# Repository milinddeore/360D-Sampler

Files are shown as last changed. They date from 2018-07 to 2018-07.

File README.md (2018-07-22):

# 360D-Sampler
Takes snaps of the product/item from 360 degree.

## Overview
If data is oil, machine learning is oil refinery! 

To generate your own image data for a specific object/product/item. We have created this project, that captures 360 degree images of an object. The work is based on the image capturing details given in the [paper](https://drive.google.com/drive/folders/0B8z-ghcMsu59RjNtS1VzN1Zpb0U) 

This sampler is meant for image sampling that can be later used for training an image classifier. To get best quality and appropriate image samples the paper concludes following: 

* Azimuth - Object should be revolved 360 degree at least 24 times in equal angle. This means 360/24 = 15 degree.
* Elevation - In a circular fashion object should be captured in four verticals i.e. 90 degree / 4 = 22.5 degree.

## Repo Contains

1. Word document that gives high level details about the sampler. 
2. Mechanical Design: CAD file of the sampler design along with BOM
3. Source code to run controller and DSLR controller software to capture pictures. 

## Working Flow

Following actions and events occur during sampling: 

1. Place the object on the revolving table top,
2. Enter the barcode so that the respective folder will be created with the name as ‘barcode #’. Else enter manual name. 
3. Follow the on-screen messages to let table top to start revolving and Cameras will start capturing images. There are total 5 cameras capturing images in tandem. 
4. Once 360 degree movement is over, the table top stops.
5. To capture another object jump to step 1.

## Physical Images Of The Sampler

Following images are of the physical sampler that was manufactured for demo purpose. 

Design



## Software

1. Arduino: To control the motor and clicker. This code is in the ‘arduino’ directory.
2. DSLR controller: This project uses libgphotos2 to control all the DSLR mounted on the hardware chassis. This code runs on the PC/Laptop and the application code is in the following path ‘slrs/examples/sample-capture.c’ 

## Compile and Install

1. Follow the [link](https://github.com/gphoto/libgphoto2/blob/master/INSTALL) to compile the code, that run on PC.   
2. Arduino code needs to be flashed onto Aruino UNO or any of the similar version. 

## Contributors
Saket Deshmukh (Saaket.deshmukh@gmail.com)
Milind Deore (tomdeore@gmail.com)

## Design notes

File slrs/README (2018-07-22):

# README #

This README would normally document whatever steps are necessary to get your application up and running.

### What is this repository for? ###

* This is DSLR based product sampler, which takes snaps of the product from 360 degree. This requires a rotating top where the product is placed while capturing pictures. This software also needs a hardware barcode scanner, optinally user can enter the product name/barcode manually too.
* This is tested version 1.0
* [Learn Markdown](https://bitbucket.org/tutorials/markdowndemo)

### How do I get set up? ###

* Summary of set up: rotating top, hardware barcode scanner, tripods and ubuntu based machine. 
* Configuration: Please see the setup.installation file for details. 
* Dependencies: None
* Database configuration: None
* How to run tests: go to ./examples/ directory of the project and run 'sample-capture' program. This program also has various options run 'sample-capture -u' to lean more.
* Deployment instructions: Follow the drawing atttached to the repo for details. 

### How to compile and install libgphotos2 and sampler application

* Compile and install as per mentioned [here](https://github.com/gphoto/libgphoto2/blob/master/INSTALL)

### Troubleshooting 

If you got this error running apt-get or some other program:
perl: warning: Setting locale failed.
perl: warning: Please check that your locale settings:

Just run this code:
export LANGUAGE=en_US.UTF-8
export LANG=en_US.UTF-8
export LC_ALL=en_US.UTF-8
locale-gen en_US.UTF-8
dpkg-reconfigure locales

### Contribution guidelines ###

* Writing tests
* Code review
* Other guidelines

### Who do I talk to? ###

* Repo owner or admin
* Other community or team contact

				   libgphoto2
				   ----------

Hello and welcome to the wonderful world of gphoto! This is libgphoto2, the 
successor of gphoto with lots of new features and additional camera
drivers. 

If you miss a feature, would like to report success or failure, or have any
questions, please don't hesitate to contact our mailing list.

What is libgphoto2?
-------------------

libgphoto2 is a library that can be used by applications to access various 
digital cameras.  

For more information on gphoto, see

        http://www.gphoto.org/

There, you can also get information on mailing lists, supported cameras,
and availability of gphoto2. Another source of information is

        https://github.com/gphoto

where you can access our SVN server to fetch the source code of
gphoto2, gtkam and GnoCam (see below).

What is libgphoto2 not?
-----------------------

libgphoto2 itself is not a GUI application, opposed to gphoto. There are
GUI frontends for the gphoto2 library, however, such as gtkam for
example.

libgphoto2 can only talk to cameras the language of those it understands.
That is, if you own a camera that speaks a language that isn't published
anywhere and nobody has been able to figure out the meaning of the sentences,
libgphoto2 cannot communicate with those cameras. 

Then, there are cameras supporting the so-called USB Mass Storage protocol.
This is a protocol that has been published and lets you access any storage
device, be it a camera or a disk connected via USB to your computer. As there
are already drivers for this protocol out there, you don't need an additional
library like libgphoto2. The list of camera that use USB Mass Storage is getting
longer everyday, so we won't publish it.

For a more up to date list, you can consult 

	http://www.teaser.fr/~hfiguiere/linux/digicam.html

Your operating system will tell you about that because it is likely to recognise
the device as a SCSI disk that you can mount (for Linux 'dmesg' will tell you).
Again, those cameras *cannot* be accessed through libgphoto2. Some of them can
be switched to use a different communication protocol and might be in that case
useable with libgphoto2.

Other camera support a protocol called PTP or USB Imaging Devices that has
been developped by Kodak and other. libgphoto2 does support PTP. Also working
will be cameras labeled as "PictBridge", which is a extension to PTP.

Almost all cameras that are not mass storage support it these days, including
but not limited to all Nikon, Canon, Fuji, Sony, Panasonic, HP and more.

PTP camera unknown to libgphoto2 will be detected as a generic PTP camera and
will work as-is without any changes.

MTP (Microsoft Transfer Protocol) capable devices will also be accessible,
since MTP is based on PTP.

Platforms
---------

libgphoto2 should compile and run on pretty much all Unix-like platforms.
libgphoto2 has _not_ (yet?) been ported to any operating system from MicroSoft.

How to set up libgphoto2
------------------------

For information on how to set up libgphoto2 and its frontends, see 
The gPhoto2 Manual.

It is available at the following places:

 - At the gphoto website: http://www.gphoto.org/

 - In the SVN module gphoto2-manual

The gPhoto2 Manual includes information about setting up USB
hotplugging.

If you run into problems, you may also consult the FAQ (also included
in The gPhoto2 Manual).

Frontends
---------

gphoto2 is a command line frontend which is quite powerful, 
especially in combination with scripts. See The gPhoto2 Manual 
for a short description. 

For the GUI lovers, there are for example digikam (KDE), gthumb (GNOME),
f-spot (GNOME / Mono) and more. We also have a GTK2 reference GUI
called gtkam, which is unmaintained, its only special features are
capture abilitiy.
Additionally, there are plugins for other programs available like
kio_camera (KDE - Konqueror) and a fuse plugin, gphotofs.

Reporting Bugs
--------------

Every piece of software contains errors and flaws. So does
libgphoto2. When you encounter something that does not work, please do
the following: 

1. Find out whether this is a known problem.

2. Reproduce the problem with debug output enabled and the language
   set to English, so that the development team will understand the
   messages. You can do this by running:

      env LC_ALL=C gtkam

   if you're using the gtkam frontend or running:

      env LC_ALL=C gphoto2 --debug-logfile=logfile.log --debug <options>

   using the gphoto2 command line interface.

3. Report the problem on the mailing list with the corresponding debug
   output if it is small. If it is more than a few kilobytes, please
   don't post the complete debug output on the list.

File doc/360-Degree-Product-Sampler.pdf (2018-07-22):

# 360 Degree Product Sampler

## High Level Design Document

Update document here (https://docs.google.com/document/d/1t0LVbnPOcXeihr9UbaT7DBcxkEmGNjN7Sz3eTbsqpfk/edit?usp=sharing)

# 1.Overview:

This document details required and design for an image sampler based on research paper. (https://drive.google.com/drive/folders/0B8z-ghcMsu59RjNtS1VzN1Zpb0U) This sampler is meant for image sampling that can be later used for training an image classifier. To get best quality and appropriate image samples the paper concludes following:

1. Azimuth - Object should be revolved 360 degree at least 24 times in equal angle. This means 360/24 = 15 degree.
2. Elevation - In a circular fashion object should be captured in four verticals i.e. 90 degree / 4 = 22.5 degree.

# 2.Product Mechanical Drawing:

There are two parts to the design:
- 360 degree revolving tray and,
- Camera arch to hold four cameras, each at 22.5 degree angle in a semi circle.

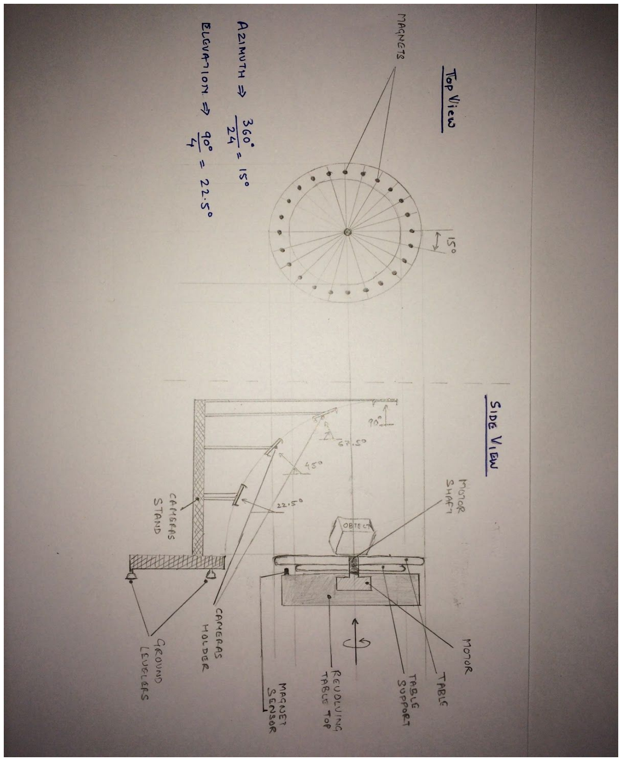
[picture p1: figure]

Revolving tray has 24 magnets each at 15 degree angle and when these magnet cross magnet-sensor, it signals camera to take a snap. These four cameras are mounted on camera stand. Each camera is angled at 22.5 degree in a circular fashion, that is radially all cameras are same distance from the object.

# 3.Bill of Material:

- Stepper motor (https://robu.in/product/nema17-40mm-1-2a-unipolar-stepper-motor-w-1m-cable/) with step size of 15 degree per step.
- Arduino UNO Board.
- Relay (https://www.amazon.in/gp/product/B00C59NOHK/ref=oh_aui_detailpage_o01_s00?ie=UTF8&psc=1)
- Lazy Susan Bearings. (http://www.amazon.in/Susan-Bearings-Thick-200-lb-Capacity/dp/B0006LBVDI)
- We can use five high speed cameras or digital cameras (DSLRs) for our purpose.

# 4.Various Circuits:

Motor, Arduino and DSLR camera all are connected to PC/Laptop via USB cable. USB HUB may be required if the port are not enough on the PC/Laptop.

The circuit has to be connected as per the specification:
1. Arduino and stepper motor interface. (https://www.tutorialspoint.com/arduino/arduino_stepper_motor.htm)
2. Other DSLR’s (http://www.doc-diy.net/photo/remote_pinout/)

# 5.Working flow:

Following actions and events occur during sampling:

1. Place the object on the revolving table,
2. Enter the barcode so that the respective folder will be created with the name as ‘barcode #’
3. Follow the on screen messages to switch ON the motor and image capturing.
4. Once 360 degree movement is over, the motor stops.
5. To capture another object jump to step 1.

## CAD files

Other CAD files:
cad_design/3d-Sampler-Mech-Design.dwg

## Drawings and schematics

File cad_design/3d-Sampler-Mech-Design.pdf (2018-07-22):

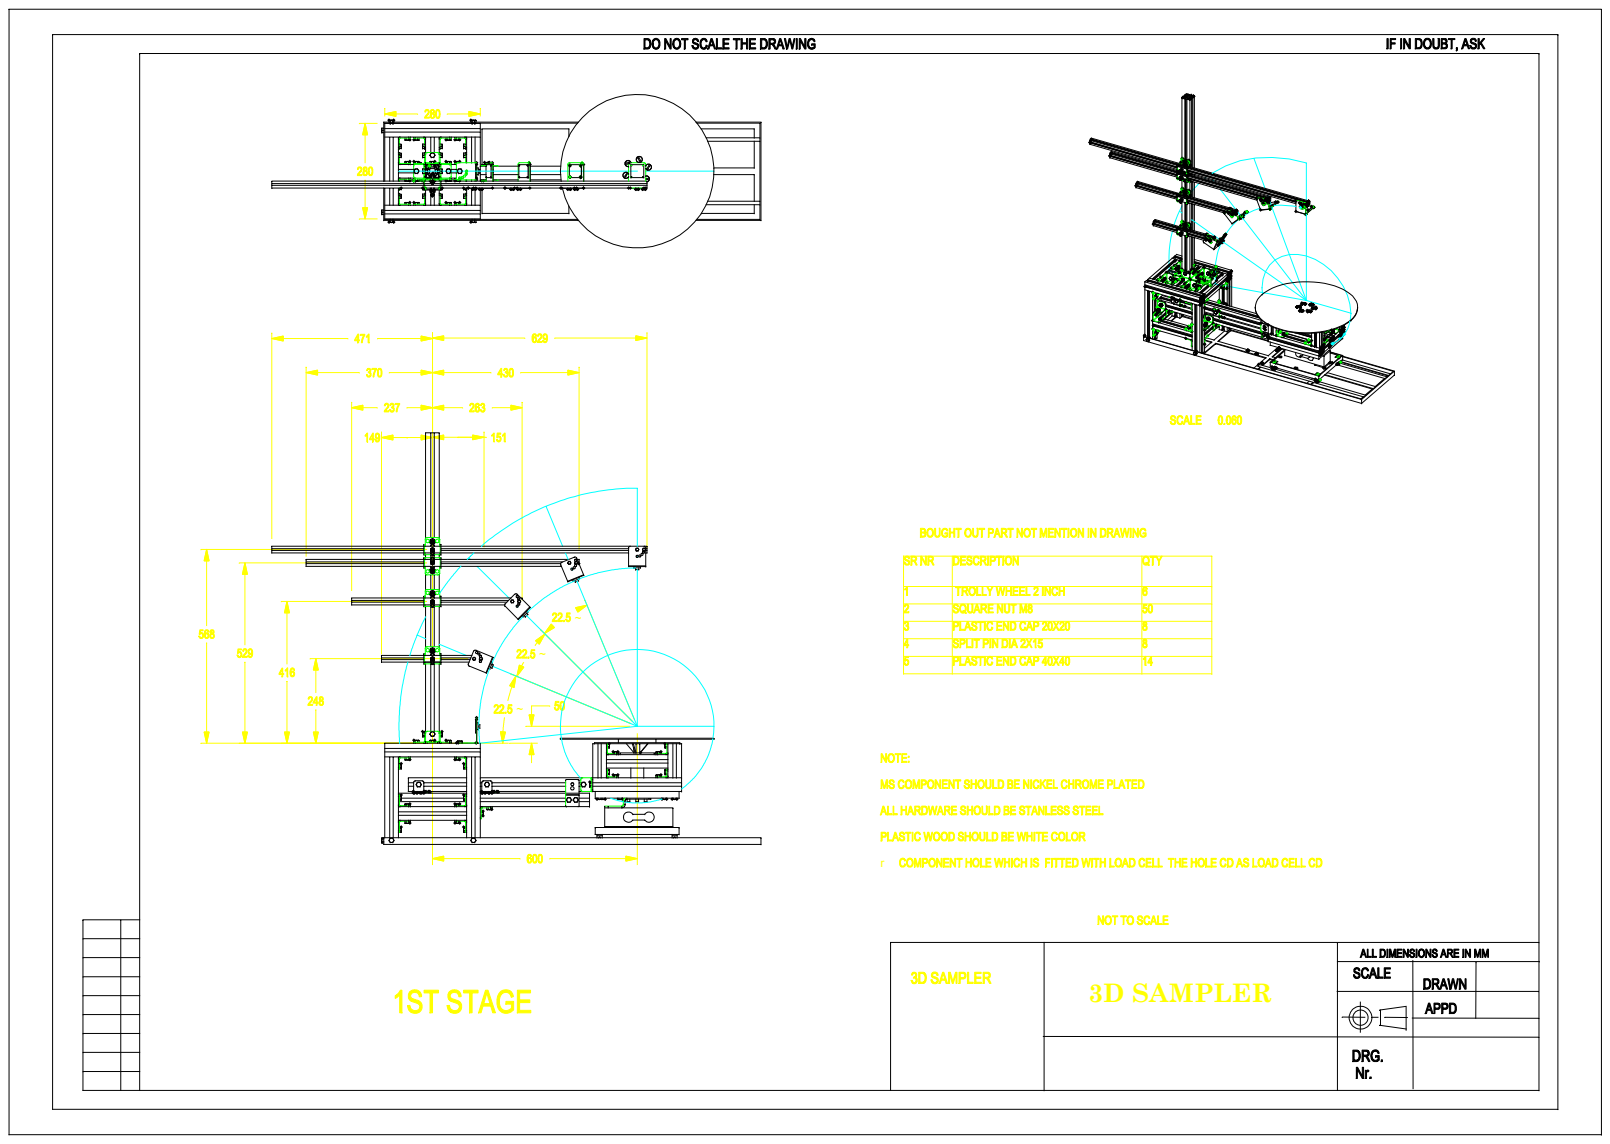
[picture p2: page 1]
3D SAMPLER

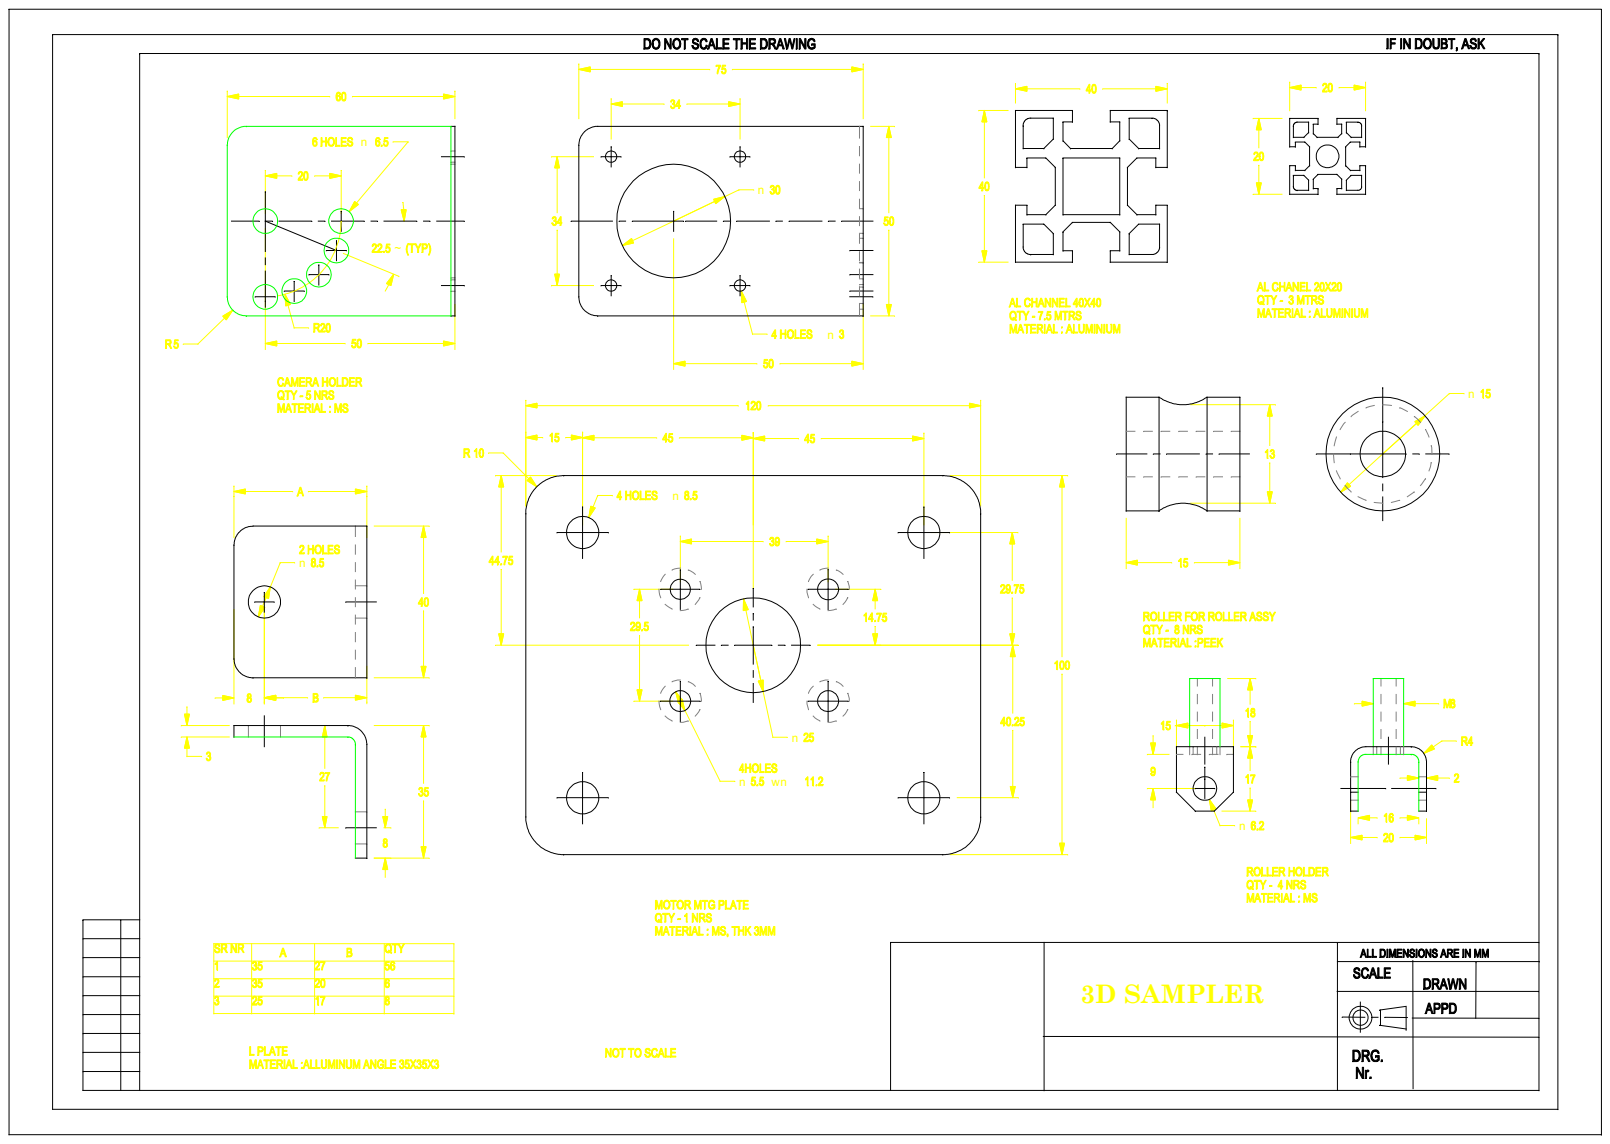
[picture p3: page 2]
3D SAMPLER

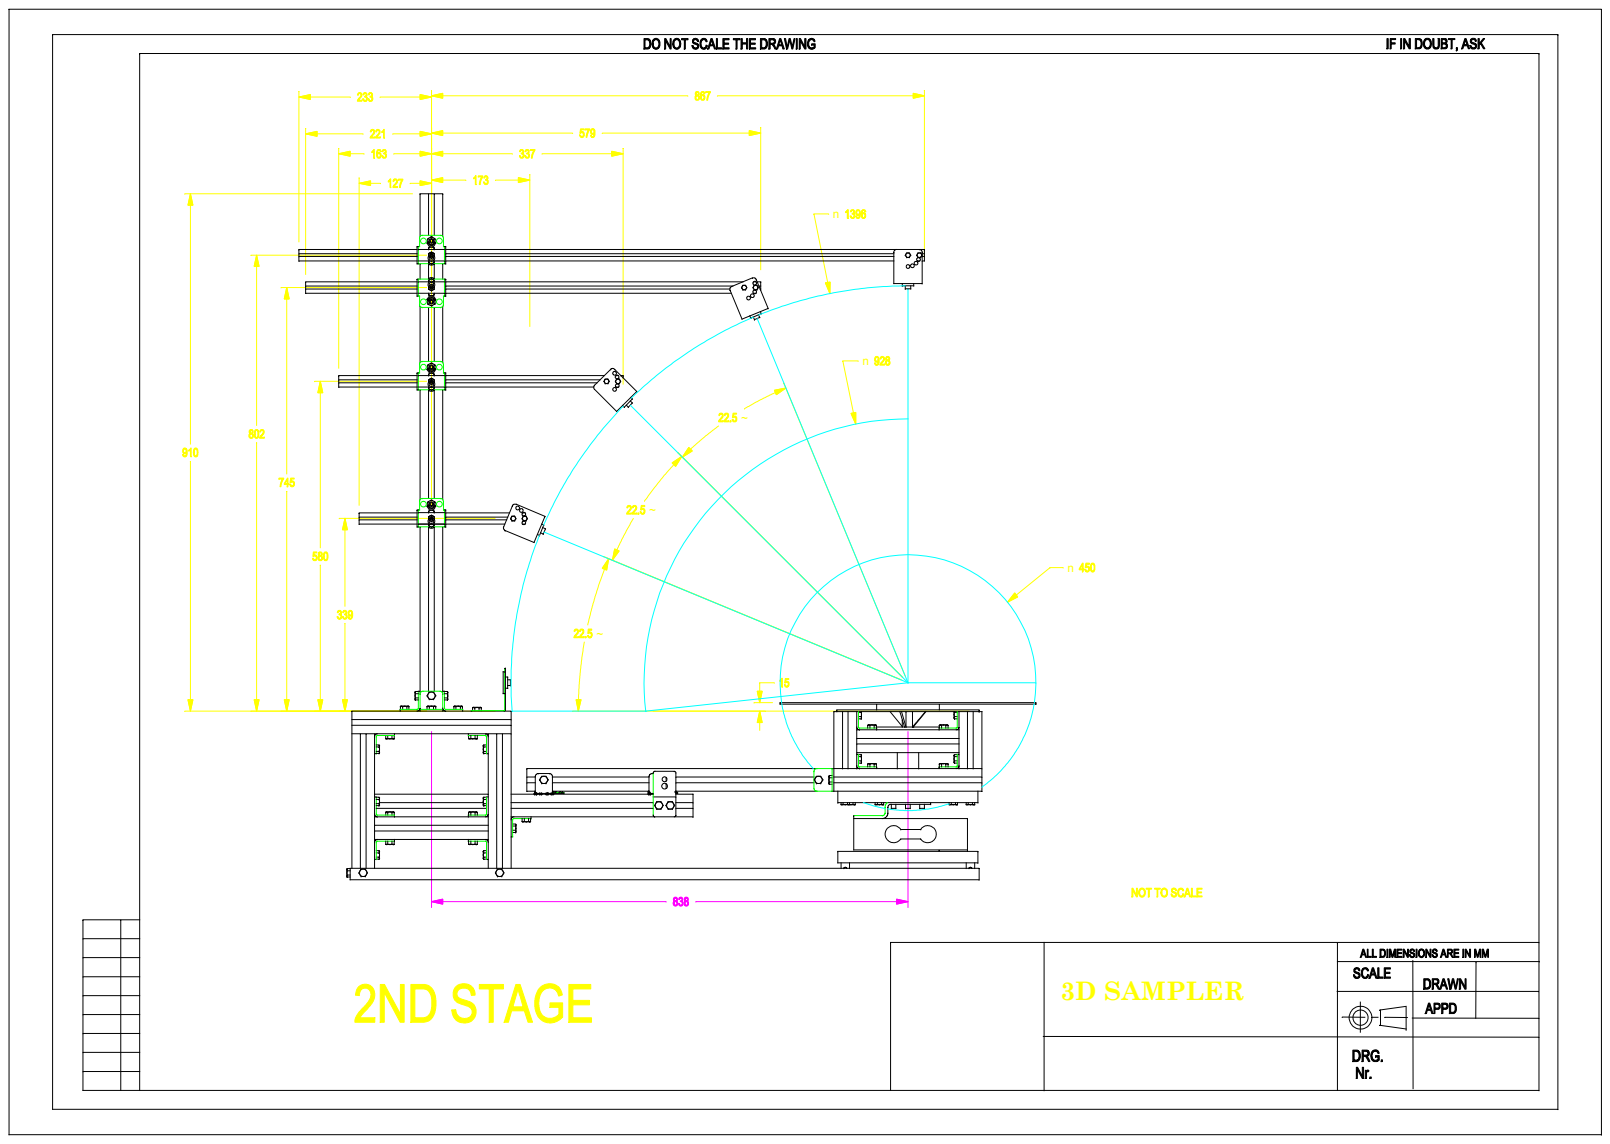
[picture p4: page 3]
3D SAMPLER

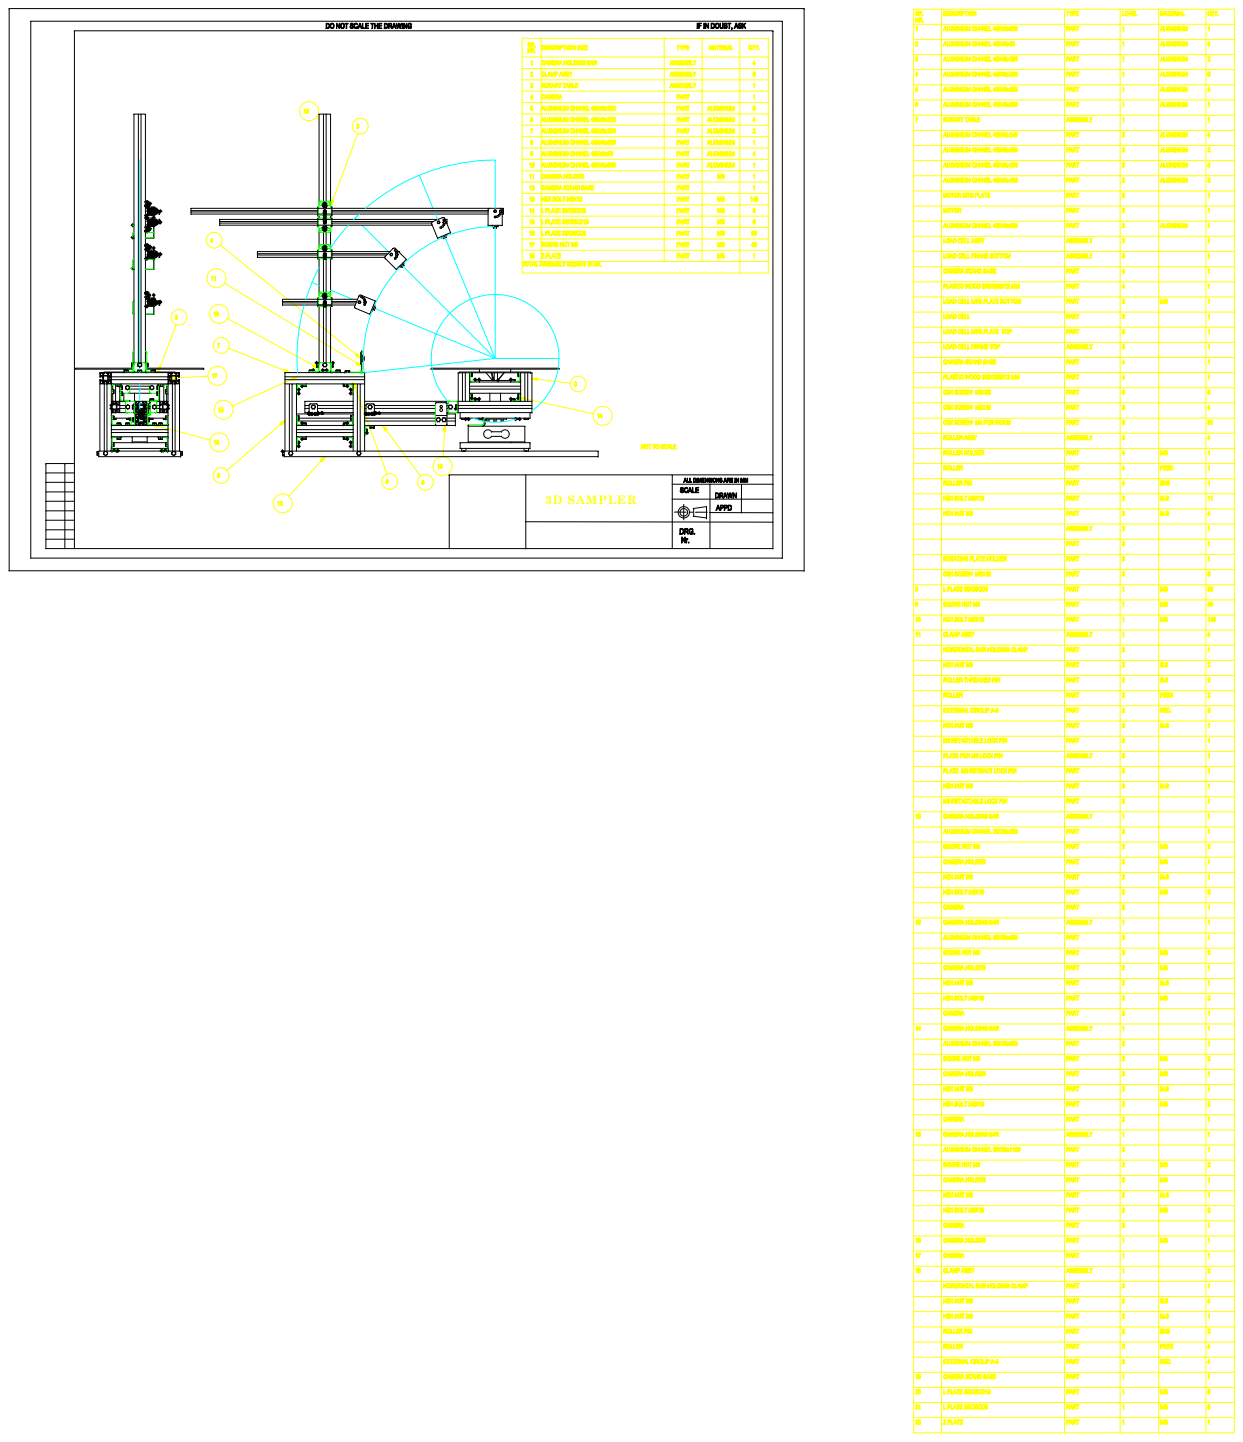
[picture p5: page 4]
3D SAMPLER

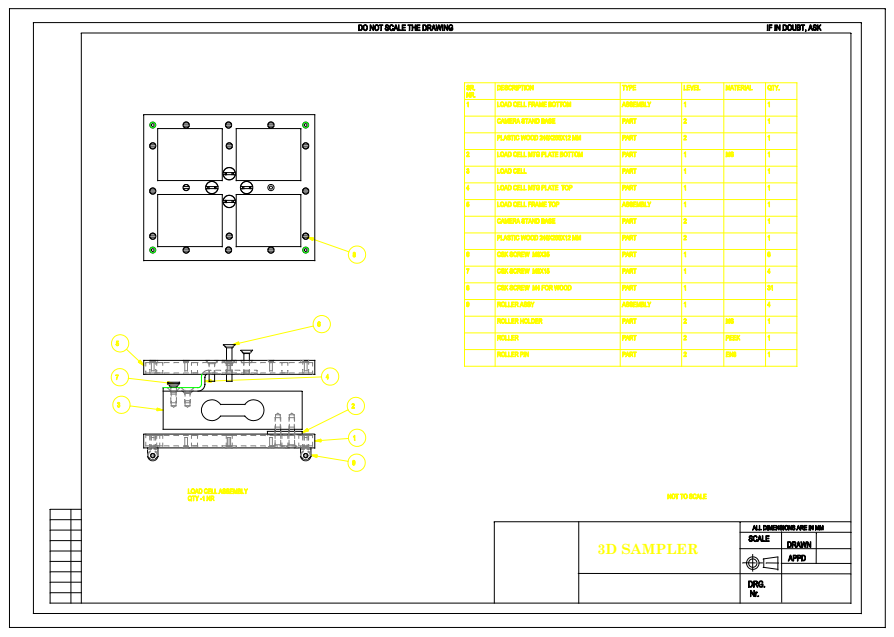
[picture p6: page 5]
3D SAMPLER

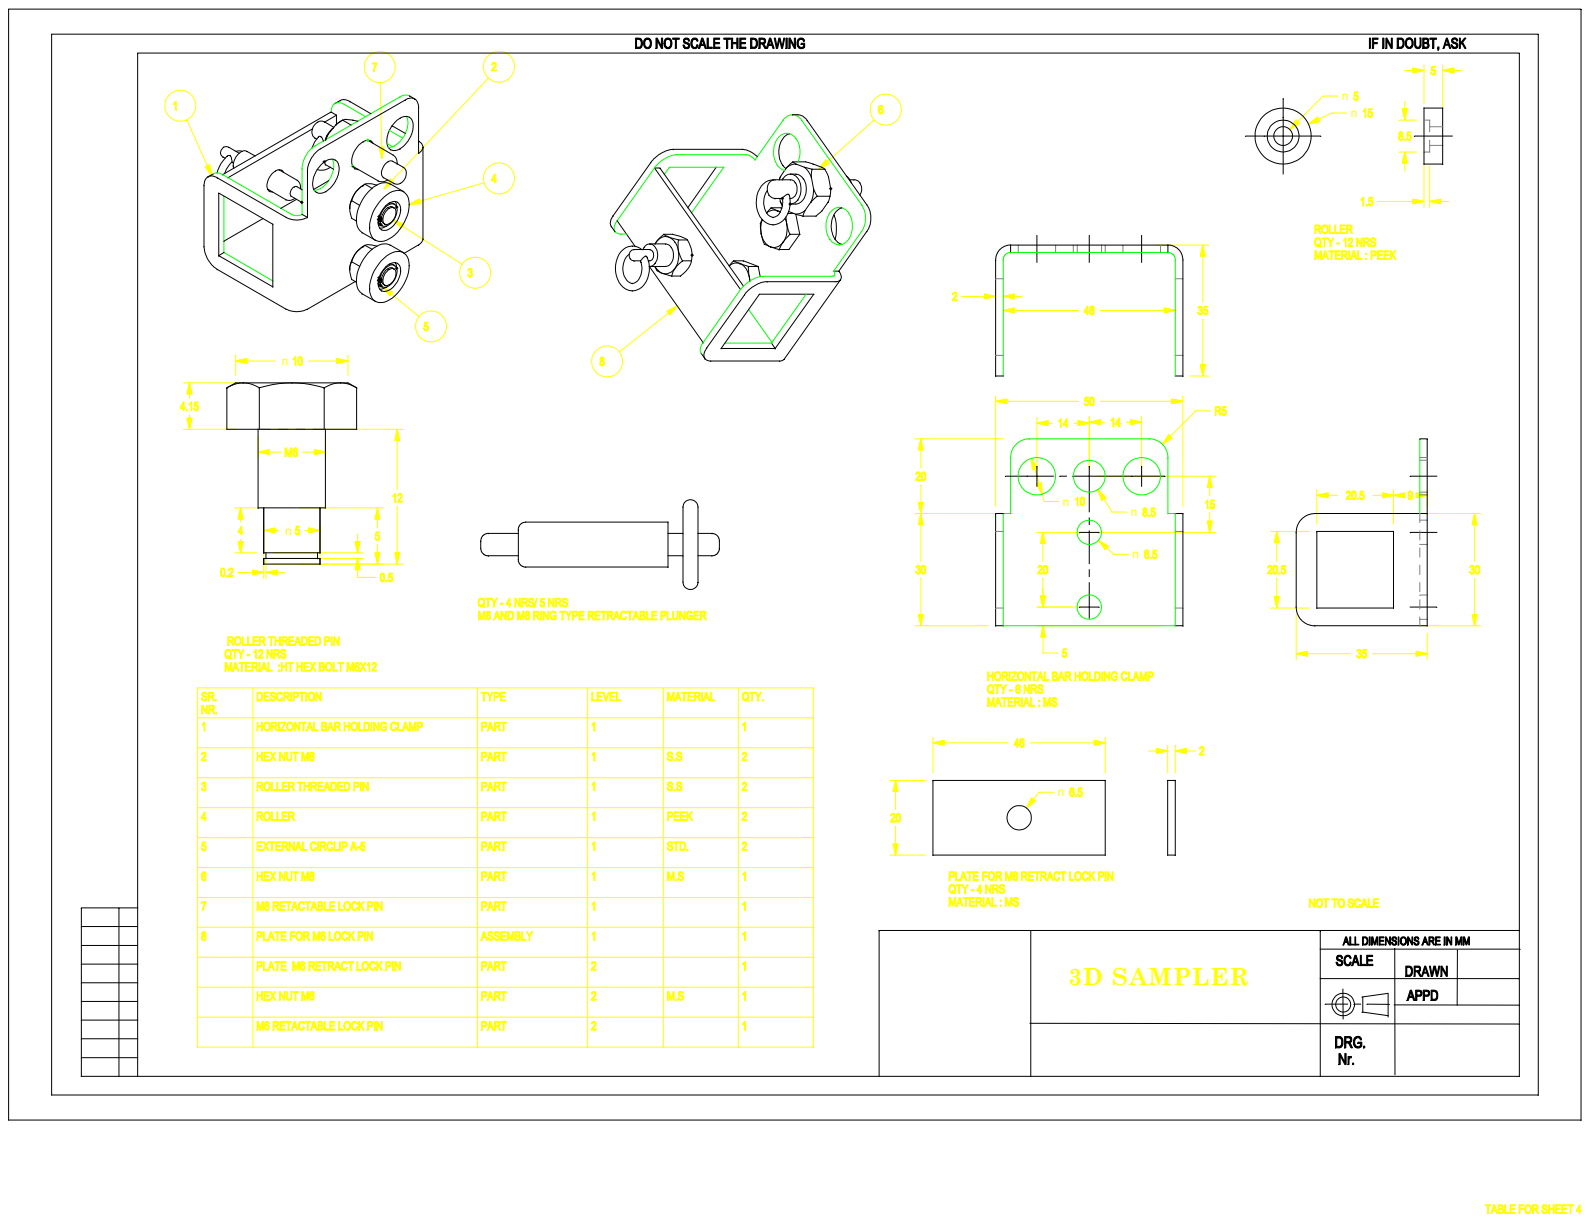
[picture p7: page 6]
3D SAMPLER

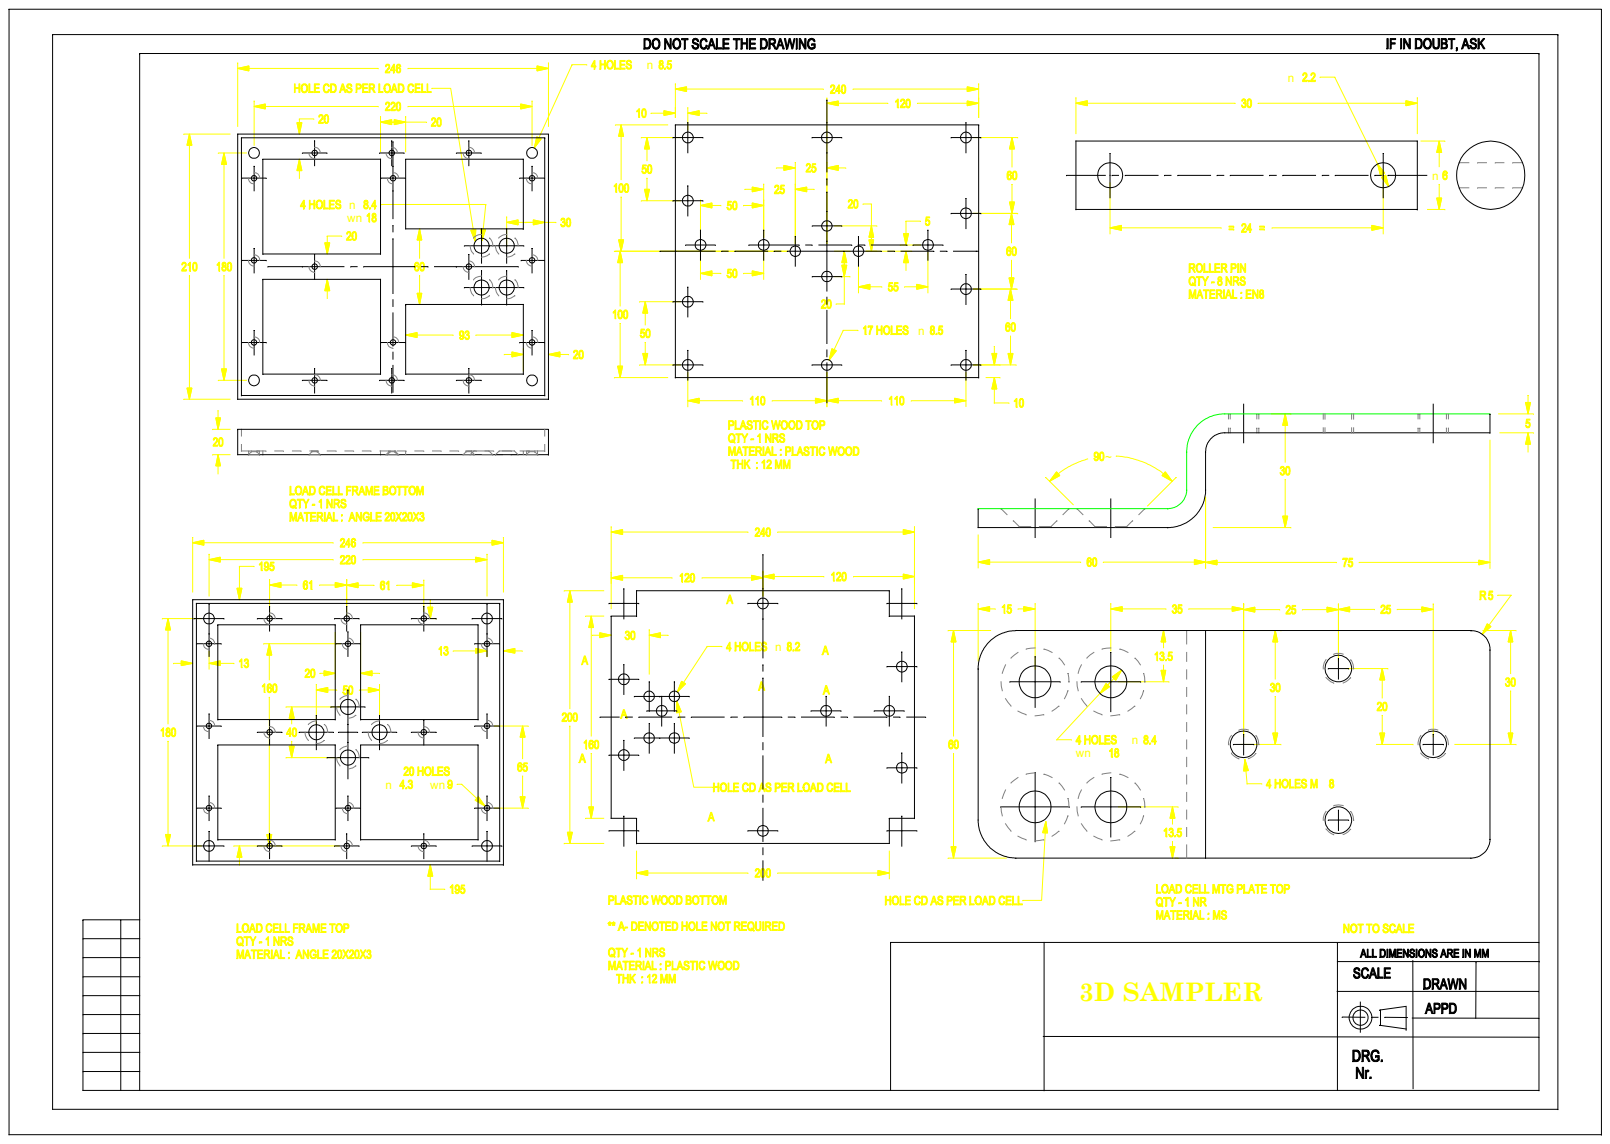
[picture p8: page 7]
3D SAMPLER

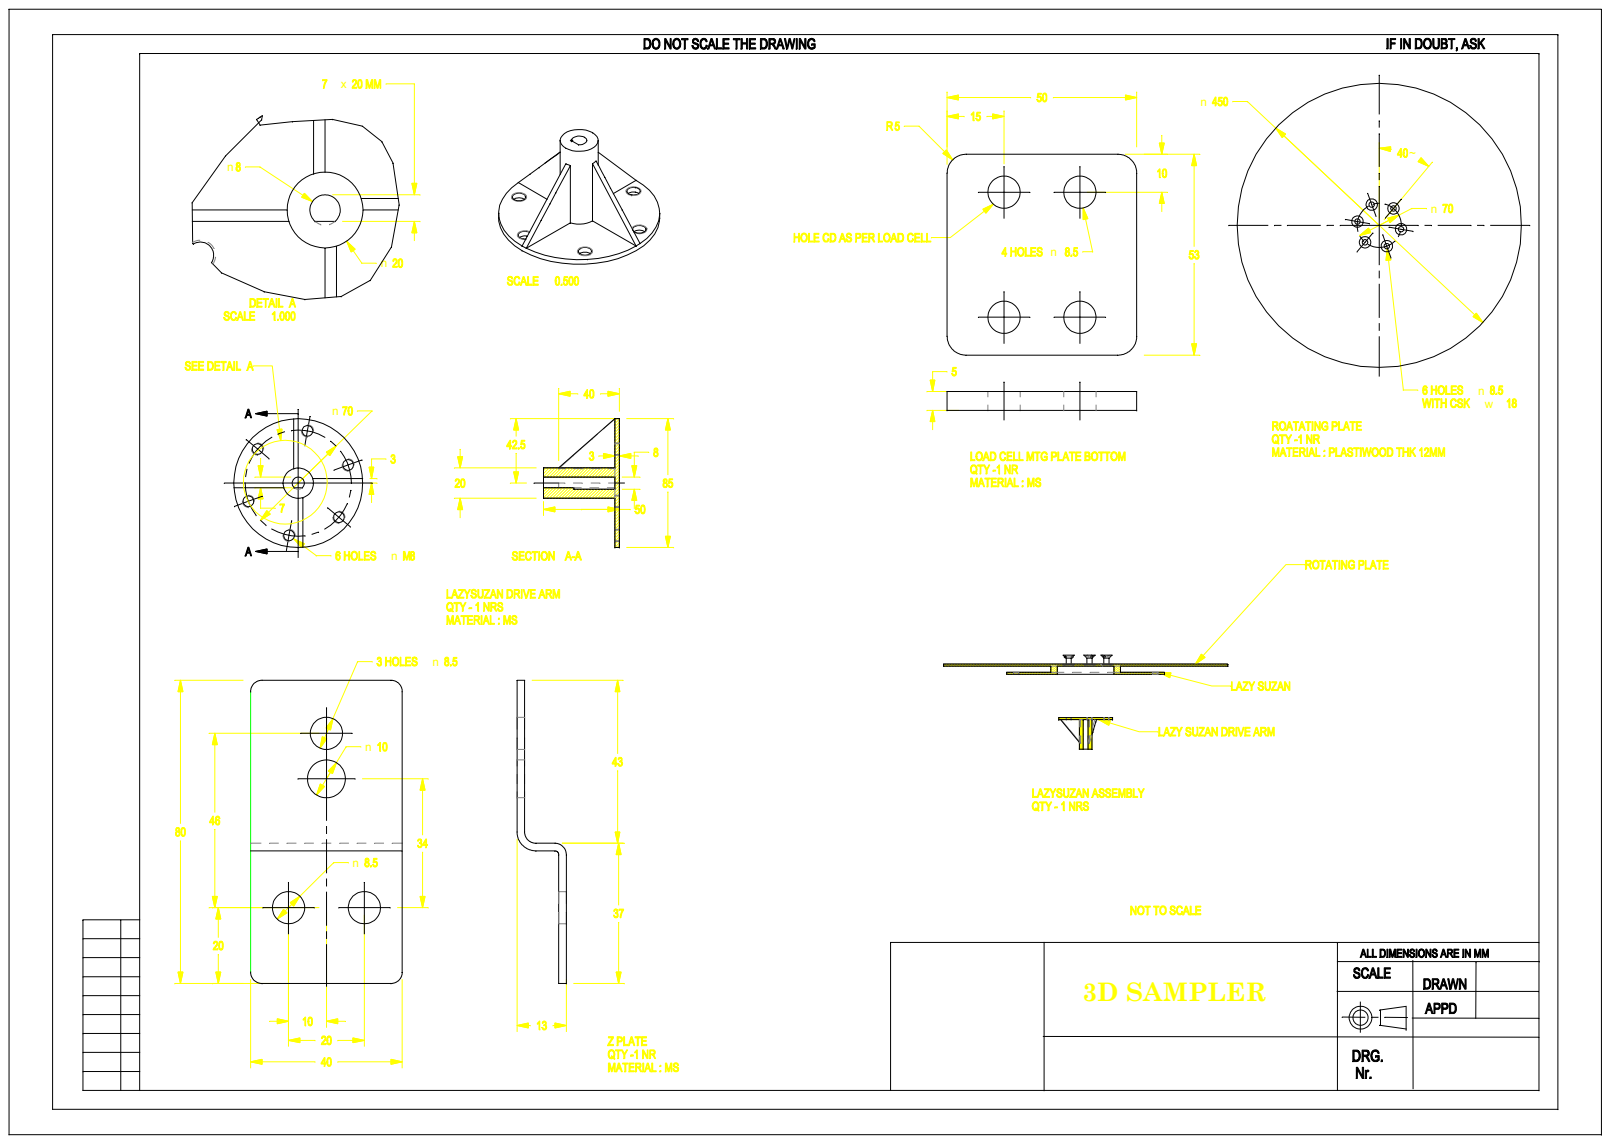
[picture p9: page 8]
3D SAMPLER

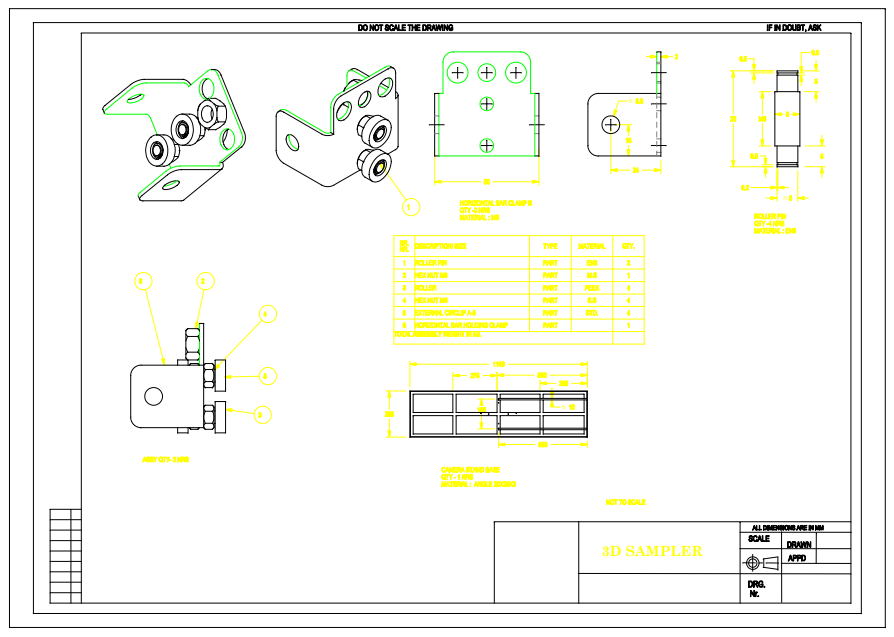
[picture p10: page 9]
3D SAMPLER

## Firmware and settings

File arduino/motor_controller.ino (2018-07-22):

/**
 * This code controls motor and responds to the clicker.  
 *
 * Number of Sensors: Barcode Reader, Picture Clicker, Motor start/stop.
 * 
 * PIN      configuration:
 * ---      --------------
 *  7       Reset pin, connect to 'Reset' pin on arduino
 *  4       Motor start/stop
 *  2       Clicker on/off
 *
 * Copyright (c) 2017 Mellowain
 * This software is released under the MIT license. See the attached LICENSE file for details.
 */
#include <Stepper.h>

/* 
 *  Calcualte steps per revolution = 360/step angle
 *  For Sampler its: 360/15 degree = 24 steps.
 */
const int stepsPerRevolution = 24;

// Initialize the stepper library on pins 8 through 11:
Stepper myStepper(stepsPerRevolution, 8, 9, 10, 11);

 

// Pins
const int MOTOR_SWITCH                = 4;        /* Motor start/stop */
const int CLICKER_ON                  = 0xF1;     /* Clicker on/off */
const int CLICKER_OFF                 = 0xF0;


// Messages between Arduino-PC
#define CARD_RESET                    ('r')
#define MOTOR_START                   ('1')
#define MOTOR_STOP                    ('2')


#define MAX_ARGC                      (5)
#define MAX_ARG_LEN                   (64)



#define DEBUG  // DEBUG or NODEBUG
#ifdef DEBUG
#define DBG_VAL(val,param)                  do {                           \
                                                 Serial.print(val, param); \
                                               } while(0);
                                  
#define DBG_MSG(msg)                        do {                           \
                                                 Serial.println(msg);      \
                                               } while(0);

#define DBG_MSG_VAL(pre_msg,val,post_msg)   do {                           \
                                                 Serial.print(pre_msg);    \
                                                 Serial.print(val);        \
                                                 Serial.println(post_msg); \
                                               } while(0);
                                    
#else
/* Disable all logs on serial console */
#define DBG_MSG_VAL(pre_msg,val,post_msg)
#define DBG_MSG(msg)
#define DBG_VAL(val,param)
#endif  // DEBUG ends

  

/* Software Reset function @ address 0 */
void (*resetCall)(void) = 0; 



/*
 * read into buffer until terminator received
 * timeout if not received within timeout_period mS
 * returns true if received within timeout period
 * returns false if not received, or no terminator received but buffer full
 */
bool read_string_until (char *data, 
                        const unsigned int length, 
                        const unsigned long timeout_period, 
                        const char terminator) 
{
                          
  unsigned int index = 0;
  unsigned long start_time = millis();
  
  while (index < length) 
  {
    /* check if time is up */
    if (millis() - start_time >= timeout_period) 
    {
       return false;  // no data in timeout period
    }

    /* if data, add to buffer */     
    if (Serial.available() > 0) 
    {
      char r = Serial.read();
      if (r == terminator) 
      {
        data [index] = 0;  // terminating null byte
        DBG_MSG("Command complete");
        return true;
      }
        data [index++] = r;
    }  
  }  
  return false;  // filled up without terminator
}


int motor_state = LOW;
int clicker_curr_state = LOW;
int stepCount = 0;         // number of steps the motor has taken

void setup() {
  Serial.begin(9600);
  // Initialize all the global variables, specially post warm reboot
  motor_state = LOW;
  clicker_curr_state = LOW;
  stepCount = 0;
  delay(500);
  DBG_MSG("Sampler is initalized!");
}


void loop() {   
  
  /* Commands based triggers */
  if(Serial.available()) 
  {
    char msg[128] = {0};

    /* Capture the incoming message */
    if (read_string_until(msg, sizeof(msg), 500, '!')) 
    {
      DBG_MSG_VAL("Rx: ", msg, "");
            
      /* Splitting string into tokens */
      char *token;
      char msg_tok[MAX_ARGC][MAX_ARG_LEN] = {0};
      byte idx = 0;
      token = strtok(msg, " ,-:;");
      while(token != NULL) 
      {
        strncat(msg_tok[idx], token, MAX_ARG_LEN - 1);
        idx++;
        token = strtok(NULL, " ,-:;");
      }
#if 0
#ifdef DEBUG
      for(idx = 0; idx < 5; idx++) 
      {
          DBG_MSG_VAL("Tokens: ", msg_tok[idx], "");
      }
#endif 
#endif
      
      /* Parsing starts here */
      if (strncmp(msg_tok[0], "START", sizeof(msg_tok)) == 0) 
      {
          DBG_MSG("Start motor");
          motor_state = HIGH;
      }
      else if (strncmp(msg_tok[0], "STOP", sizeof(msg_tok)) == 0) 
      {
          DBG_MSG("Stop motor");
          motor_state = LOW;
      }
      else if(strncmp(msg_tok[0], "ACK", sizeof(msg_tok)) == 0) 
      {
          DBG_MSG("Clicker done taking pictures"); 
          clicker_curr_state = LOW;;
      }
      else if(strncmp(msg_tok[0], "RESET", sizeof(msg_tok)) == 0) 
      {
          DBG_MSG("Card Reset called"); 
          motor_state = LOW;
          clicker_curr_state = LOW;
          stepCount = 0;
      }
      else if(strncmp(msg_tok[0], "REBOOT", sizeof(msg_tok)) == 0) 
      {
          DBG_MSG("Card Reboot called"); 
          setup();
      }
      else 
      {
          DBG_MSG("ERROR: Invalid command!");           
      }
    } 
  }
  
  
  if(motor_state) {
    
    if (clicker_curr_state)
    {
      DBG_MSG_VAL("Clicker ON, Steps: ", stepCount, "");
      byte buf[1] = {CLICKER_ON};
      Serial.write(buf, 1);
    }
    else
    {
      myStepper.step(1);
      DBG_MSG("clicker armed again");
      stepCount++;
      clicker_curr_state = HIGH;
    }
  }
}

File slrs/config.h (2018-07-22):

/* config.h.  Generated from config.h.in by configure.  */
/* config.h.in.  Generated from configure.ac by autoheader.  */

/* Define if building universal (internal helper macro) */
/* #undef AC_APPLE_UNIVERSAL_BUILD */

/* Whether we have flex and bison for GP2DDB */
/* #undef ENABLED_GP2DDB */

/* Define to 1 if translation of program messages to the user's native
   language is requested. */
#define ENABLE_NLS 1

/* The gettext domain we're using */
#define GETTEXT_PACKAGE "libgphoto2-6"

/* Define if there is asm .symver support. */
#define HAVE_ASM_SYMVERS 1

/* The C compiler we're using */
#define HAVE_CC "gcc"

/* Define if the GNU dcgettext() function is already present or preinstalled.
   */
#define HAVE_DCGETTEXT 1

/* Define to 1 if you have the <dirent.h> header file, and it defines `DIR'.
   */
#define HAVE_DIRENT_H 1

/* Define to 1 if you have the <dlfcn.h> header file. */
#define HAVE_DLFCN_H 1

/* Define to 1 if you have the `getenv' function. */
#define HAVE_GETENV 1

/* Define to 1 if you have the `getopt' function. */
#define HAVE_GETOPT 1

/* Define to 1 if you have the <getopt.h> header file. */
#define HAVE_GETOPT_H 1

/* Define to 1 if you have the `getopt_long' function. */
#define HAVE_GETOPT_LONG 1

/* Define if the GNU gettext() function is already present or preinstalled. */
#define HAVE_GETTEXT 1

/* Define to 1 if you have the `gmtime_r' function. */
#define HAVE_GMTIME_R 1

/* Define if you have the iconv() function. */
#define HAVE_ICONV 1

/* Define to 1 if you have the `inet_aton' function. */
#define HAVE_INET_ATON 1

/* Define to 1 if you have the <inttypes.h> header file. */
#define HAVE_INTTYPES_H 1

/* Define to 1 if you have the <langinfo.h> header file. */
#define HAVE_LANGINFO_H 1

/* whether we compile with libexif support */
/* #undef HAVE_LIBEXIF */

/* whether we use a version of libexif with ExifData.ifd[[]] */
/* #undef HAVE_LIBEXIF_IFD */

/* whether we compile with gdlib support */
/* #undef HAVE_LIBGD */

/* Define to 1 if you have the `ibs' library (-libs). */
/* #undef HAVE_LIBIBS */

/* define if we found LIBJPEG and its headers */
#define HAVE_LIBJPEG 1

/* whether we compile with libxml-2.0 support */
#define HAVE_LIBXML2 1

/* Define to 1 if you have the <limits.h> header file. */
#define HAVE_LIMITS_H 1

/* Define to 1 if you have the <locale.h> header file. */
#define HAVE_LOCALE_H 1

/* Define to 1 if you have the `localtime_r' function. */
#define HAVE_LOCALTIME_R 1

/* Define to 1 if you have the `lstat' function. */
#define HAVE_LSTAT 1

/* Whether libltdl (of libtool fame) is present */
#define HAVE_LTDL 1

/* Define to 1 if you have the <mcheck.h> header file. */
#define HAVE_MCHECK_H 1

/* Define to 1 if you have the <memory.h> header file. */
#define HAVE_MEMORY_H 1

/* Define to 1 if you have the `mkdir' function. */
#define HAVE_MKDIR 1

/* Define to 1 if you have the <ndir.h> header file, and it defines `DIR'. */
/* #undef HAVE_NDIR_H */

/* Define to 1 if you have the `rand_r' function. */
#define HAVE_RAND_R 1

/* Define to 1 if you have the `setenv' function. */
#define HAVE_SETENV 1

/* Define to 1 if you have the `snprintf' function. */
#define HAVE_SNPRINTF 1

/* Define to 1 if you have the `sprintf' function. */
#define HAVE_SPRINTF 1

/* Define to 1 if you have the `statfs' function. */
#define HAVE_STATFS 1

/* Define to 1 if you have the <stdint.h> header file. */
#define HAVE_STDINT_H 1

/* Define to 1 if you have the <stdlib.h> header file. */
#define HAVE_STDLIB_H 1

/* Define to 1 if you have the `strcpy' function. */
#define HAVE_STRCPY 1

/* Define to 1 if you have the `strdup' function. */
#define HAVE_STRDUP 1

/* Define to 1 if you have the <strings.h> header file. */
#define HAVE_STRINGS_H 1

/* Define to 1 if you have the <string.h> header file. */
#define HAVE_STRING_H 1

/* Define to 1 if you have the `strncpy' function. */
#define HAVE_STRNCPY 1

/* Define to 1 if `f_bavail' is a member of `struct statfs'. */
#define HAVE_STRUCT_STATFS_F_BAVAIL 1

/* Define to 1 if `f_bfree' is a member of `struct statfs'. */
#define HAVE_STRUCT_STATFS_F_BFREE 1

/* Define to 1 if `f_favail' is a member of `struct statfs'. */
/* #undef HAVE_STRUCT_STATFS_F_FAVAIL */

/* Define to 1 if `f_blocks' is a member of `struct statvfs'. */
/* #undef HAVE_STRUCT_STATVFS_F_BLOCKS */

/* Define to 1 if you have the <sys/dir.h> header file, and it defines `DIR'.
   */
/* #undef HAVE_SYS_DIR_H */

/* Define to 1 if you have the <sys/mman.h> header file. */
#define HAVE_SYS_MMAN_H 1

/* Define to 1 if you have the <sys/mount.h> header file. */
#define HAVE_SYS_MOUNT_H 1

/* Define to 1 if you have the <sys/ndir.h> header file, and it defines `DIR'.
   */
/* #undef HAVE_SYS_NDIR_H */

/* Define to 1 if you have the <sys/param.h> header file. */
#define HAVE_SYS_PARAM_H 1

/* Define to 1 if you have the <sys/select.h> header file. */
#define HAVE_SYS_SELECT_H 1
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
